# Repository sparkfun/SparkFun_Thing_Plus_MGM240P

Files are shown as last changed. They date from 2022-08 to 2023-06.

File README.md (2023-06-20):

SparkFun Thing Plus Matter - MGM240P
========================================

SparkFun Thing Plus Matter - MGM240P (https://www.sparkfun.com/products/20270)

[*SparkFun Thing Plus Matter - MGM240P (DEV-20270)*](https://www.sparkfun.com/products/20270)

The SparkFun Thing Plus Matter - MGM240P . The MGM3240P wireless module from Silicon Labs<sup>&reg;</sup> provides secure connectivity for both 802.15.4 and Bluetooth<sup>&reg;</sup> Low Energy 5.3 protocols. The module comes ready for integration into Silicon Labs' [Matter](https://www.silabs.com/wireless/matter) IoT protocol for home automation. SparkFun's [Thing Plus](https://www.sparkfun.com/thing_plus) development boards are Feather-compatible and include a Qwiic connector for easy integration into our Qwiic Connect System for solderless I<sup>2</sup>C circuits.

The SparkFun Thing Plus Matter - MGM240P includes Qwiic and LiPo battery connectors, multiple GPIO pins capable of complete multiplexing through software. The board also features the MCP73831 single-cell LiPo charger as well as the MAX17048 fuel gauge to charge and monitor a connected battery. Lastly, we've included a &micro;SD card slot for any external memory needs.

Repository Contents
-------------------

* **/Documentation** - Data sheets, additional product information
* **/Hardware** - Eagle design files (.brd, .sch)
* **/Production** - Production panel files (.brd)

Documentation
--------------
* **[Hookup Guide](https://learn.sparkfun.com/tutorials/sparkfun-thing-plus-matter---mgm240p-hookup-guide)** - Basic hookup guide for the Thing Plus Matter - MGM240P.
* **[Fritzing Part](https://github.com/sparkfun/Fritzing_Parts/blob/main/products/20270_sfe_thing_plus_matter_mgm240p.fzpz)** -  Fritzing diagrams for SparkFun products.

Product Versions
----------------
* [DEV-20270](https://www.sparkfun.com/products/20270)- Initial release of the Thing Plus Matter - MGM240P 

License Information
-------------------

This product is _**open source**_! 

Please review the LICENSE.md file for license information. 

If you have any questions or concerns on licensing, please contact technical support on our [SparkFun forums](https://forum.sparkfun.com/viewforum.php?f=152).

Distributed as-is; no warranty is given.

- Your friends at SparkFun.

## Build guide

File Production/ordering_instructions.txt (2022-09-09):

panel size, 107x201mm
PCB thickness, 1.6mm
number of layers, 4
soldermask color, Red
silkscreen color, White
oz copper, 1oz
finish, ENIG
stencils, top+bottom
pcs per panel, 12
min trace width, 0.1270mm / 0.0050in
min drill size, 0.3048mm / 0.0120in
filename to layer stackup 1/2/3/4: GTL, GL2, GL3, GBL

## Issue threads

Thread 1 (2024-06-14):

Onboard JLink UART issue

SiarheiVolkau, 2024-06-14:
I'm actually have no hope that this issue will be fixed someday, just want to warn everyone that
This piece of hardware can't be used for roles like NCP/RCP (Network/Radio Co-Processor)
because integrated onboard JLink debugger, which also tries to act as USB-to-TTL converter,
unable to do UART conversion properly.

It drops a lot of data transmitted by the MGM240 and sends a few bytes of obscure data every two seconds to MGM240
thus using any OpenThread CLI example or act as co-processor become impossible for this device, only with external debugger/USB-to-TTL converter it became feasible.

sfe-SparkFro, 2024-06-17:
Hi there, sorry to hear you're having trouble!

Could you please elaborate on what exactly you're doing to test this? I tried a quick test on my end and am unable to replicate what you describe.

For reference, I'm using the 2.0.0 release of the [SiLabs Arduino boards package](https://github.com/SiliconLabs/arduino/releases), and I uploaded the following sketch:

```
void setup() {
  Serial.begin(115200);
  Serial.println("Hello world!");
}

void loop() {
  if(Serial.available())
    Serial.print((char) Serial.read());
}
```

> sends a few bytes of obscure data every two seconds to MGM240

This is a simple serial echo sketch, which works as expected on my end. This should also detect and print any erroneous data coming from the debugger, but I've had it running for several minutes without anything unexpected happening. I've also been looking at the TX/RX pins with an oscilloscope, and the scope hasn't detected anything from the debugger.

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

The MGM240P does appear to send a couple erroneous bytes when it boots up (indicated by the 2 box symbols at the start), but that shouldn't have any effect while in operation.

Perhaps you can try doing this as well to see if your board is behaving different from mine?

> It drops a lot of data transmitted by the MGM240

I haven't tested this part yet, but given that I'm unable to replicate the above, I suspect the root problem may be something else in your setup, or your board is somehow different from mine.

Hope this helps! If you're able to test what I did above, would be great to hear your results! Thanks!

SiarheiVolkau, 2024-06-18:
Sure, here is my setup:
ArchLinux on the host PC (Silabs udev rules installed).
Simplicity Studio 5 with Gecko SDK 4.4.3 (older SDKs tried as well).
Simplicity Commander, used for flashing.

The project is the example called `Platform - I/O Stream USART Bare-metal` with no modifications.
Build it then flash via Simplicity Commander.
Use UART via minicom/picocom to communicate with the example by UART:
e.g. `picocom -b 115200 /dev/ttyACM0`
I saw `~` symbols in the output periodically and output might stop for a while.

Unfortunately for this issue, fortunately for me I can't reproduce this issue anymore, all of mine devices
start working as expected. So I'm closing this issue until I can reproduce it again.

Thanks for quick response.

sfe-SparkFro, 2024-06-18:
Thanks for sharing that info! If it does come up again, please follow up with replication instructions so we can try to figure out the root problem. I suspect, and I hope, that the problem is not with the J-Link chip, but would need to do more testing to actually determine that.

Closed 2024-06-18.

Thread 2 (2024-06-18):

Change baudrate on integrated USB-to-UART

SiarheiVolkau, 2024-06-18:
Is there any way to do so?
I'm able to change baudrate in the source code.
And say communication program to set specific baudrate (picocom).

But it seems 115200 is the only working setup.

It's crucial to get faster baudrates if this device used as network / radio coprocessor as it dramatically reduces latencies.

My setup:
- ArchLinux
- Simplicity Studio v5
- Gecko SDK 4.4.3
- `iostream-usart-baremetal` example used, with changed baudrate to 230400 in `IO Stream: USART (vcom)` software component.
- `picocom -b 230400 /dev/ttyACM0`

sfe-SparkFro, 2024-06-18:
I am also seeing this, using the same Arduino sketch I shared in #1. I will follow up with SiLabs to see if other baud rates can be selected.

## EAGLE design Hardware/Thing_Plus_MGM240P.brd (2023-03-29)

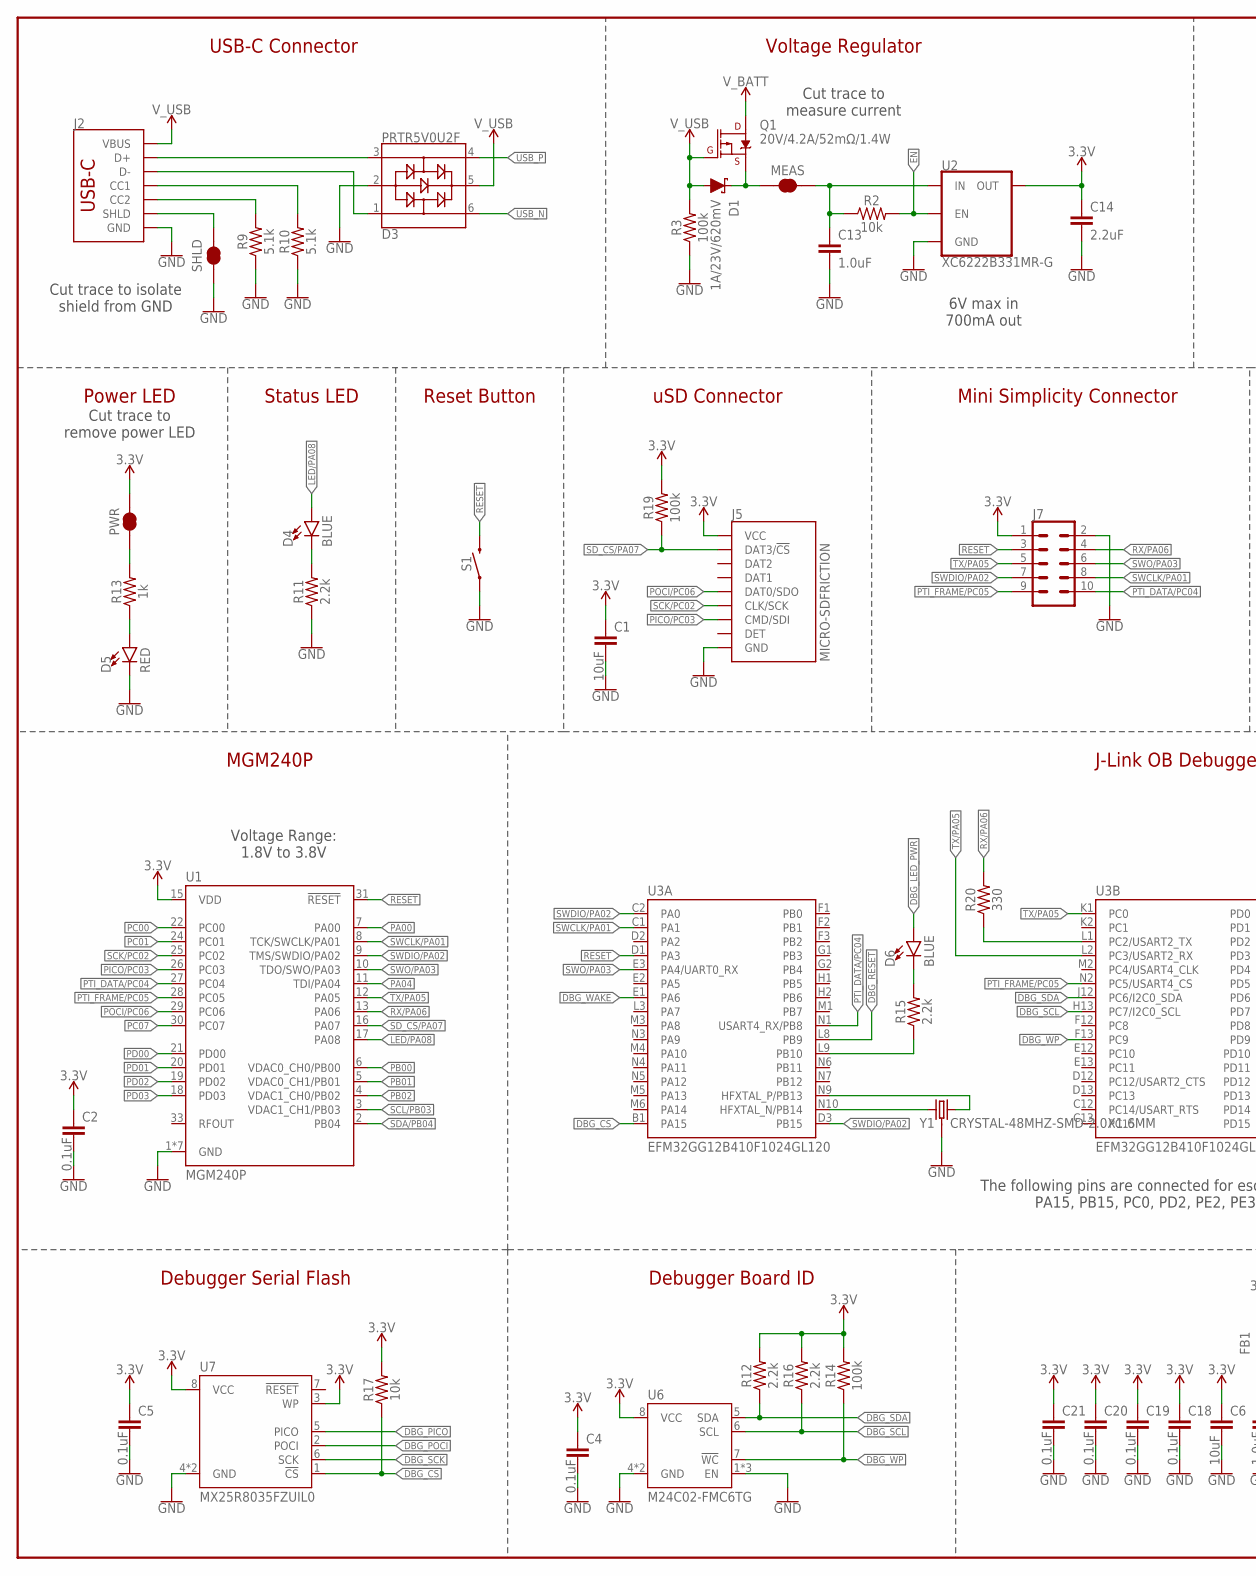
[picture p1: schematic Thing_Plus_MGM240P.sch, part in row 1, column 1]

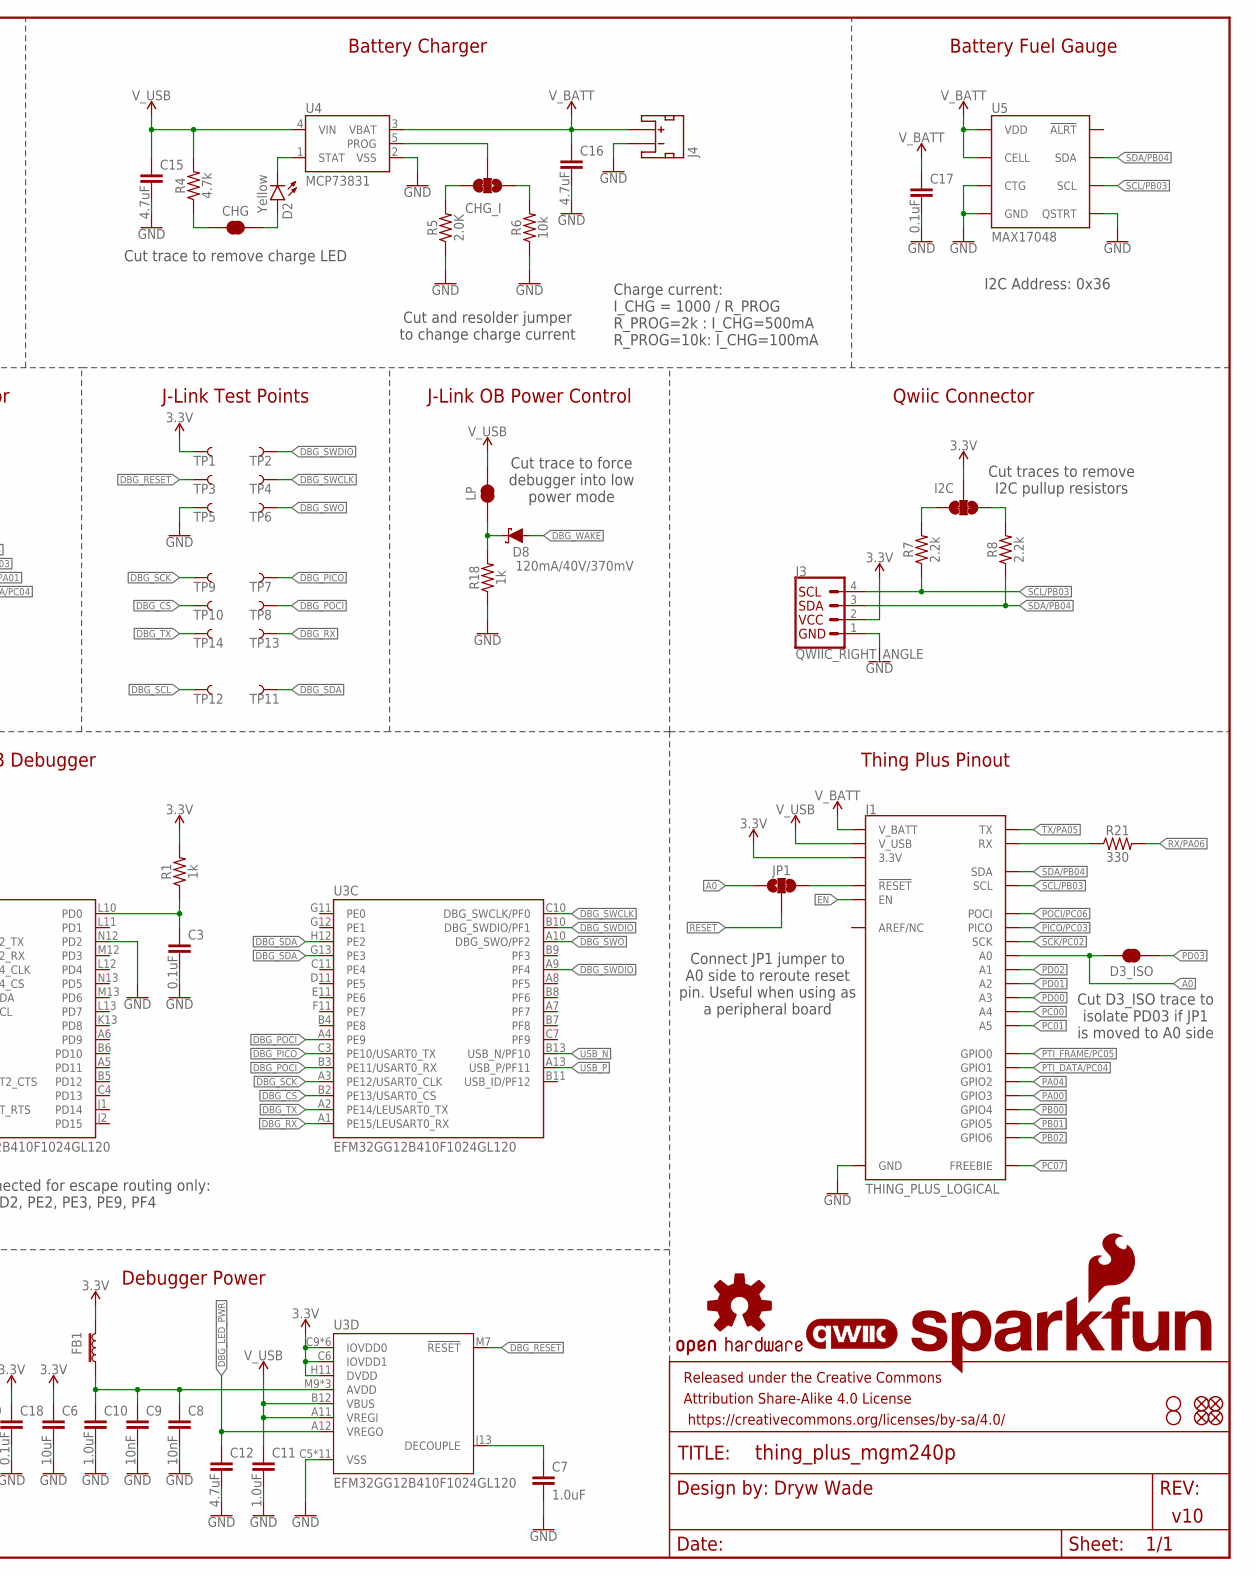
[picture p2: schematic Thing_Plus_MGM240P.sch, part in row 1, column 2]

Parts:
C1, C6: 10uF; 0402-TIGHT
C2, C3, C4, C5, C17, C18, C19, C20, C21: 0.1uF; 0402-TIGHT
C7: 1.0uF; 0603
C8, C9: 10nF; 0402-TIGHT
C10, C11, C13: 1.0uF; 0402-TIGHT
C12, C15, C16: 4.7uF; 0402-TIGHT
C14: 2.2uF; 0402-TIGHT
CHG: JUMPER-SMT_2_NC_TRACE_SILK; SMT-JUMPER_2_NC_TRACE_SILK
CHG_I: JUMPER-SMT_3_1-NC_TRACE_SILK; SMT-JUMPER_3_1-NC_TRACE_SILK
D1: 1A/23V/620mV; SOD-323
D2: Yellow; LED-0603
D3: PRTR5V0U2F; SOT886
D3_ISO: JUMPER-SMT_2_NC_TRACE_SILK; SMT-JUMPER_2_NC_TRACE_SILK
D4, D6: BLUE; LED-0603
D5: RED; LED-0603
D8: 120mA/40V/370mV; SOD-523
FB1: FERRITE_BEAD-120_OHM-0402T; 0402-TIGHT
FD1, FD2, FD3, FD4: FIDUCIAL1X2; FIDUCIAL-1X2
FRAME1: FRAME-LEDGER; CREATIVE_COMMONS
H1, H2: STAND-OFF
I2C: JUMPER-SMT_3_2-NC_TRACE_SILK; SMT-JUMPER_3_2-NC_TRACE_SILK
J1: THING_PLUS_LOGICAL; THING_PLUS
J2: USB Female Type C Connector; USB-C-16P-4LAYER-ISOLATED
J3: QWIIC_RIGHT_ANGLE; JST04_1MM_RA
J4: JST_2MM_MALE; JST-2-SMD
J5: MICRO-SDFRICTION; MICROSD_TINY
J7: CONN_05X20.05_IN_PTH_SILK; 2X5_PTH_SILK_.05
JP1: JUMPER-SMT_3_1-NC_TRACE_SILK; SMT-JUMPER_3_1-NC_TRACE_SILK
LOGO1: SFE_LOGO_NAME_FLAME.1_INCH; SFE_LOGO_NAME_FLAME_.1
LOGO2: QWIIC_LOGO_3MM; QWIIC_3MM
LOGO3: OSHW-LOGOS; OSHW-LOGO-S
LP: JUMPER-SMT_2_NC_TRACE_SILK; SMT-JUMPER_2_NC_TRACE_SILK
MEAS: JUMPER-COMBO_2_NC_TRACE; COMBO-JUMPER_2_NC_TRACE
PWR: JUMPER-SMT_2_NC_TRACE_SILK; SMT-JUMPER_2_NC_TRACE_SILK
Q1: 20V/4.2A/52mΩ/1.4W; SOT23-3
R1, R13, R18: 1k; 0402-TIGHT
R2, R6, R17: 10k; 0402-TIGHT
R3, R14, R19: 100k; 0402-TIGHT
R4: 4.7k; 0402-TIGHT
R5: 2.0K; 0402-TIGHT
R7, R8, R11, R12, R15, R16: 2.2k; 0402-TIGHT
R9, R10: 5.1k; 0402-TIGHT
R20, R21: 330; 0402-TIGHT
S1: MOMENTARY-SWITCH-SPST-SMD-4.6X2.8MM; TACTILE_SWITCH_SMD_4.6X2.8MM
SHLD: JUMPER-SMT_2_NC_TRACE_SILK; SMT-JUMPER_2_NC_TRACE_SILK
TP1, TP2, TP3, TP4, TP5, TP6, TP7, TP8, TP9, TP10, TP11, TP12, TP13, TP14: TEST-POINT3; PAD.03X.03
U1: MGM240P
U2: XC6222B331MR-G; SOT23-5
U3: EFM32GG12B410F1024GL120; BGA120
U4: MCP73831; SOT23-5
U5: MAX17048; DFN-8
U6: M24C02-FMC6TG; DFN8_2X3MM
U7: MX25R8035FZUIL0; USON-8_2X3MM
Y1: CRYSTAL-48MHZ-SMD-2.0X1.6MM; CRYSTAL-SMD-2.0X1.6MM-ECS

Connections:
3.3V: C1.1, C2.1, C4.1, C5.1, C6.1, C14.1, C18.1, C19.1, C20.1, C21.1, FB1.2, I2C.2, J1.27 (3.3V), J3.2, J5.4 (VCC), J7.1, PWR.2, R1.2, R12.2, R14.2, R16.2, R17.2, R19.2, TP1.1, U1.15 (VDD), U2.5 (OUT), U3.C6 (IOVDD1), U3.C9 (IOVDD0), U3.G3 (IOVDD0), U3.H11 (DVDD), U3.J11 (IOVDD0), U3.K3 (IOVDD0), U3.L4 (IOVDD0), U3.L7 (IOVDD0), U6.8 (VCC), U7.3 (WP), U7.8 (VCC)
!DBG_RESET!: TP3.1, U3.L8 (PB9), U3.M7 (!RESET!)
!RESET!: J7.3, JP1.2, S1.3 (2), S1.4 (2), U1.31 (!RESET!), U3.D1 (PA3)
!SD_CS!/PA07: J5.2 (DAT3/!CS!), R19.1, U1.16 (PA07)
A0: D3_ISO.2, J1.24 (A0), JP1.1
DBG_CS: R17.1, TP10.1, U3.B1 (PA15), U3.B2 (PE13/USART0_CS), U7.1 (!CS!)
DBG_LED_PWR: C12.1, D6.A, U3.A12 (VREGO)
DBG_PICO: TP7.1, U3.C3 (PE10/USART0_TX), U7.5 (PICO)
DBG_POCI: TP8.1, U3.A4 (PE9), U3.B3 (PE11/USART0_RX), U7.2 (POCI)
DBG_RX: TP13.1, U3.A1 (PE15/LEUSART0_RX)
DBG_SCK: TP9.1, U3.A3 (PE12/USART0_CLK), U7.6 (SCK)
DBG_SCL: R16.1, TP12.1, U3.H13 (PC7/I2C0_SCL), U6.6 (SCL)
DBG_SDA: R12.1, TP11.1, U3.G13 (PE3), U3.H12 (PE2), U3.J12 (PC6/I2C0_SDA), U6.5 (SDA)
DBG_SWCLK: TP4.1, U3.C10 (DBG_SWCLK/PF0)
DBG_SWDIO: TP2.1, U3.A9 (PF4), U3.B10 (DBG_SWDIO/PF1)
DBG_SWO: TP6.1, U3.A10 (DBG_SWO/PF2)
DBG_TX: TP14.1, U3.A2 (PE14/LEUSART0_TX)
DBG_WAKE: D8.A, U3.E1 (PA6)
DBG_WP: R14.1, U3.F13 (PC9), U6.7 (!WC!)
EN: J1.11 (EN), R2.2, U2.3 (EN)
GND: C1.2, C2.2, C3.2, C4.2, C5.2, C6.2, C7.2, C8.2, C9.2, C10.2, C11.2, C12.2, C13.2, C14.2, C15.2, C16.2, C17.2, C18.2, C19.2, C20.2, C21.2, D3.2, D5.C, J1.25 (GND), J2.GND, J2.GND2 (GND), J3.1, J4.1 (-), J5.6 (GND), J5.GND1 (GND), J5.GND2 (GND), J5.GND3 (GND), J5.GND4 (GND), J5.GND5 (GND), J5.GND6 (GND), J7.2, R3.1, R5.1, R6.1, R9.1, R10.1, R11.1, R18.1, S1.1, S1.2 (1), SHLD.1, TP5.1, U1.1 (GND), U1.14 (GND), U1.23 (GND), U1.32 (GND), U1.34 (GND), U1.35 (GND), U1.36 (GND), U2.2 (GND), U3.C5 (VSS), U3.C8 (VSS), U3.H3 (VSS), U3.J3 (VSS), U3.K11 (VSS), U3.K12 (VSS), U3.L5 (VSS), U3.L6 (VSS), U3.M8 (VSS), U3.M11 (VSS), U3.N8 (VSS), U3.N12 (PD2), U4.2 (VSS), U5.1 (CTG), U5.4 (GND), U5.6 (QSTRT), U5.9 (GND), U6.1 (EN), U6.2 (EN), U6.3 (EN), U6.4 (GND), U6.EPAD (GND), U7.4 (GND), U7.EPAD (GND), Y1.2 (GND), Y1.4 (GND)
LED/PA08: D4.A, U1.17 (PA08)
unnamed: D4.C, R11.2
unnamed: PWR.1, R13.2
unnamed: CHG.2, D2.A
unnamed: CHG_I.1, R6.2
unnamed: D2.C, U4.1 (STAT)
unnamed: CHG_I.3, R5.2
unnamed: D1.C, MEAS.1, MEAS.3 (1), Q1.2 (S)
unnamed: D5.A, R13.1
unnamed: CHG_I.2, U4.5 (PROG)
unnamed: CHG.1, R4.1
unnamed: I2C.3, R7.2
unnamed: C3.1, R1.1, U3.L10 (PD0)
unnamed: I2C.1, R8.2
unnamed: J2.B5 (CC2), R9.2
unnamed: J2.A5 (CC1), R10.2
unnamed: D3.3, J2.A6 (D+), J2.B6 (D+)
unnamed: C7.1, U3.J13 (DECOUPLE)
unnamed: D3.1, J2.A7 (D-), J2.B7 (D-)
unnamed: C8.1, C9.1, C10.1, FB1.1, U3.M9 (AVDD), U3.M10 (AVDD), U3.N11 (AVDD)
unnamed: R15.1, U3.L9 (PB10)
unnamed: D6.C, R15.2
unnamed: U3.N10 (HFXTAL_N/PB14), Y1.1
unnamed: U3.N9 (HFXTAL_P/PB13), Y1.3 (2)
unnamed: D8.C, LP.1, R18.2
unnamed: R20.1, U3.L1 (PC2/USART2_TX)
unnamed: J1.15 (RX), R21.1
unnamed: C13.1, MEAS.2, MEAS.4 (2), R2.1, U2.1 (IN)
unnamed: J1.28 (!RESET), JP1.3
PA00: J1.6 (GPIO3), U1.7 (PA00)
PA04: J1.7 (GPIO2), U1.11 (TDI/PA04)
PB00: J1.5 (GPIO4), U1.6 (VDAC0_CH0/PB00)
PB01: J1.4 (GPIO5), U1.5 (VDAC0_CH1/PB01)
PB02: J1.3 (GPIO6), U1.4 (VDAC1_CH0/PB02)
PC00: J1.20 (A4), U1.22 (PC00)
PC01: J1.19 (A5), U1.24 (PC01)
PC07: J1.13 (FREEBIE), U1.30 (PC07)
PD00: J1.21 (A3), U1.21 (PD00)
PD01: J1.22 (A2), U1.20 (PD01)
PD02: J1.23 (A1), U1.19 (PD02)
PD03: D3_ISO.1, U1.18 (PD03)
PICO/PC03: J1.17 (PICO), J5.3 (CMD/SDI), U1.26 (PC03)
POCI/PC06: J1.16 (POCI), J5.7 (DAT0/SDO), U1.29 (PC06)
PTI_DATA/PC04: J1.8 (GPIO1), J7.10, U1.27 (PC04), U3.N1 (USART4_RX/PB8)
PTI_FRAME/PC05: J1.9 (GPIO0), J7.9, U1.28 (PC05), U3.N2 (PC5/USART4_CS)
RX/PA06: J7.4, R20.2, R21.2, U1.13 (PA06)
SCK/PC02: J1.18 (SCK), J5.5 (CLK/SCK), U1.25 (PC02)
SCL/PB03: J1.2 (SCL), J3.4, R7.1, U1.3 (VDAC1_CH1/PB03), U5.7 (SCL)
SDA/PB04: J1.1 (SDA), J3.3, R8.1, U1.2 (PB04), U5.8 (SDA)
SHLD: J2.SHLD1 (SHLD), J2.SHLD2 (SHLD), J2.SHLD3 (SHLD), J2.SHLD4 (SHLD), J2.SHLD5 (SHLD), J2.SHLD6 (SHLD), J2.SHLD7 (SHLD), J2.SHLD8 (SHLD), SHLD.2
SWCLK/PA01: J7.8, U1.8 (TCK/SWCLK/PA01), U3.C1 (PA1)
SWDIO/PA02: J7.7, U1.9 (TMS/SWDIO/PA02), U3.C2 (PA0), U3.D3 (PB15)
SWO/PA03: J7.6, U1.10 (TDO/SWO/PA03), U3.E3 (PA4/UART0_RX)
TX/PA05: J1.14 (TX), J7.5, U1.12 (PA05), U3.K1 (PC0), U3.L2 (PC3/USART2_RX)
USB_N: D3.6, U3.B13 (USB_N/PF10)
USB_P: D3.4, U3.A13 (USB_P/PF11)
V_BATT: C16.1, C17.1, J1.12 (V_BATT), J4.2 (+), Q1.3 (D), U4.3 (VBAT), U5.2 (CELL), U5.3 (VDD)
V_USB: C11.1, C15.1, D1.A, D3.5, J1.10 (V_USB), J2.VBUS1 (VBUS), J2.VBUS2 (VBUS), LP.2, Q1.1 (G), R3.2, R4.2, U3.A11 (VREGI), U3.B12 (VBUS), U4.4 (VIN)

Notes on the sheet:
Voltage Regulator
Battery Charger
Battery Fuel Gauge
USB-C Connector
I2C Address: 0x36
Cut trace to remove charge LED
Charge current: I_CHG = 1000 / R_PROG R_PROG=2k : I_CHG=500mA R_PROG=10k: I_CHG=100mA
Cut and resolder jumper to change charge current
6V max in 700mA out
Cut trace to isolate shield from GND
Cut trace to measure current
Qwiic Connector
uSD Connector
Cut traces to remove I2C pullup resistors
Mini Simplicity Connector
Status LED
J-Link Test Points
J-Link OB Debugger
Thing Plus Pinout
MGM240P
J-Link OB Power Control
Dryw Wade
v10
Cut trace to remove power LED
Reset Button
Power LED
Voltage Range: 1.8V to 3.8V
Debugger Serial Flash
Debugger Board ID
Debugger Power
Cut trace to force debugger into low power mode
Connect JP1 jumper to A0 side to reroute reset pin. Useful when using as a peripheral board
Cut D3_ISO trace to isolate PD03 if JP1 is moved to A0 side
The following pins are connected for escape routing only: PA15, PB15, PC0, PD2, PE2, PE3, PE9, PF4

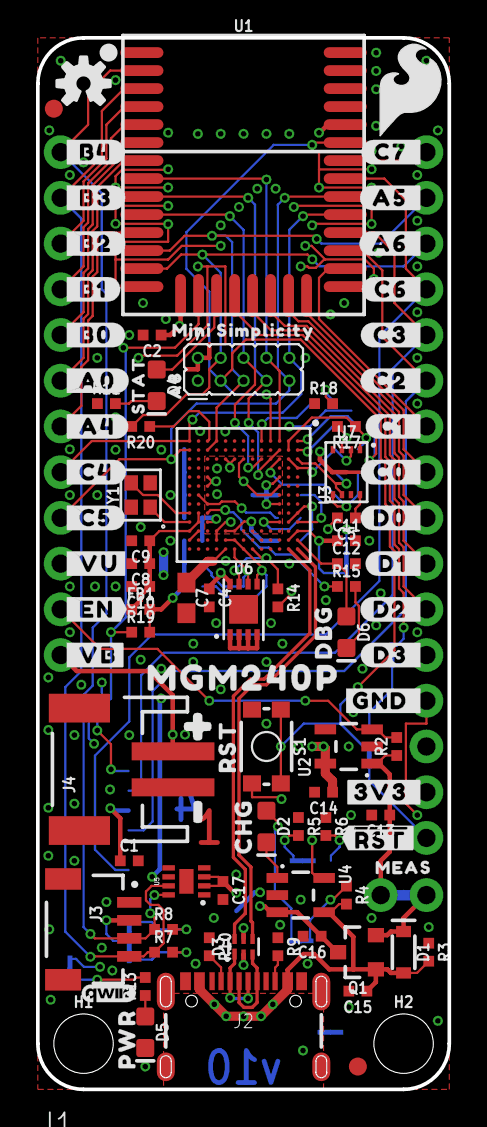
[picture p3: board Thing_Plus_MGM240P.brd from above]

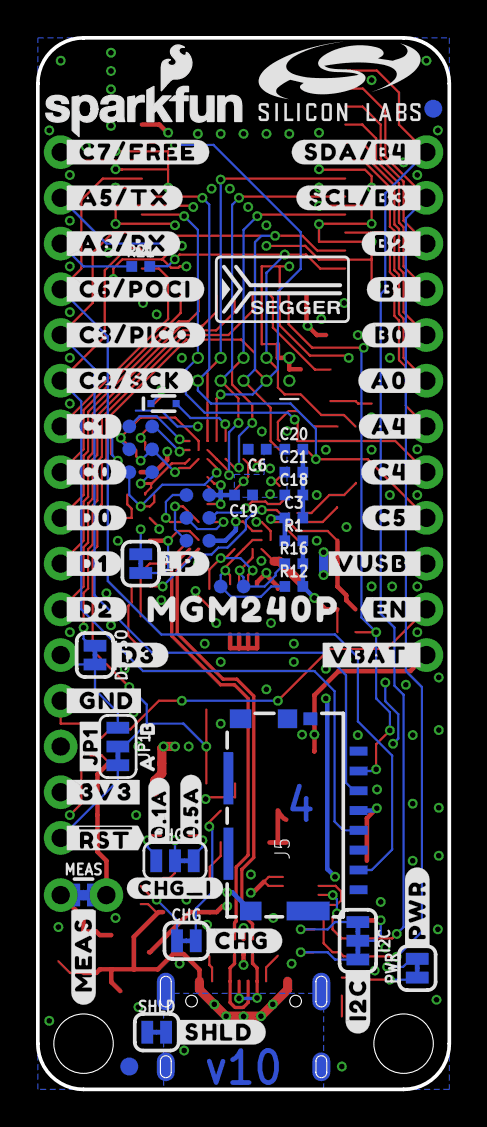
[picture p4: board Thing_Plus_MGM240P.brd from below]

Board: 4 copper layers, 22.9 x 58.4 mm, 182 parts (80 on the bottom side), 79 nets.

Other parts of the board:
U$1: #_B4#0
U$2: #_B3#0
U$3: #_B2#0
U$4: #_B1#0
U$5: #SHLD#0
U$6: #_B0#0
U$7: #_A0#0
U$8: #_A4#0
U$9: #_C5#0
U$10: #_C4#0
U$11: #C7_#0
U$12: #A5_#0
U$13: #A6_#0
U$14: #C6_#0
U$15: #C3_#0
U$16: #C2_#0
U$17: #C1_#0
U$18: #C0_#0
U$19: #PWR#0
U$20: PWR0
U$21: #GND_#0
U$22: #3V3_#0
U$23, U$58: MGM240P0
U$24: #D0_#0
U$25: #_VB#0
U$26: #_VU#0
U$27: #_EN#0
U$28: ##RST##0
U$29: SFE_LOGO_FLAME_.2
U$30: #0
U$31: #1
U$32: #D1_#0
U$33: #LP#0
U$34: #_A6#RX#0
U$35: #_C6#POCI#0
U$36: #_C3#PICO#0
U$37: #_C2#SCK#0
U$38: MINI_SIMPLICITY0
U$39: #_C1#0
U$40: #_C0#0
U$41: #_D0#0
U$42: #_D1#0
U$43: #_GND#0
U$44: #_3V3#0
U$45: #_#RST##0
U$46: #_D2#0
U$47: SEGGER_LOGO_7.5MM
U$48: #C4_#0
U$49: #C5_#0
U$50: #A4_#0
U$51: #A0_#0
U$52: #B0_#0
U$53: #B2_#0
U$54: #B1_#0
U$55: #VBAT_#0
U$56: #VUSB_#0
U$57: #EN_#0
U$59: #MEAS#0
U$60: #CHG#0
U$61: #I2C#0
U$62: #D2_#0
U$63: #0#5A#0
U$64: #0#1A#0
U$66: MEAS81
U$67: CHG0
U$68: STAT0
U$69: #JP1#0
U$70: RST0
U$71: #_A5#TX#0
U$72: A80
U$73: #SDA#B4_#0
U$74: #SCL#B3_#0
U$75: ORDERING_INSTRUCTIONS
U$76: FOUR_LAYER_WARNING
U$77: #D3_#0
U$78: DBG0
U$79: #_C7#FREE#0
U$80: A0
U$81: B0
U$82: #D3#4
U$83: #CHG_I#0
U$84: SILICON_LABS_LOGO_9MM

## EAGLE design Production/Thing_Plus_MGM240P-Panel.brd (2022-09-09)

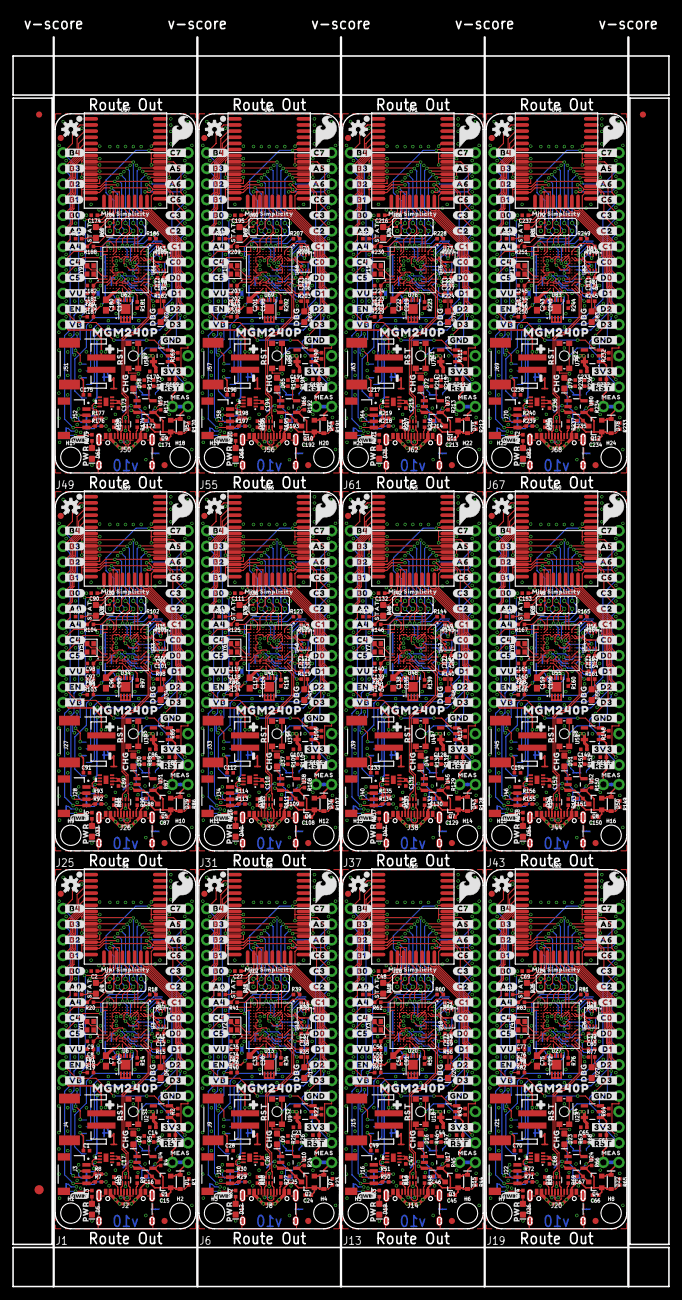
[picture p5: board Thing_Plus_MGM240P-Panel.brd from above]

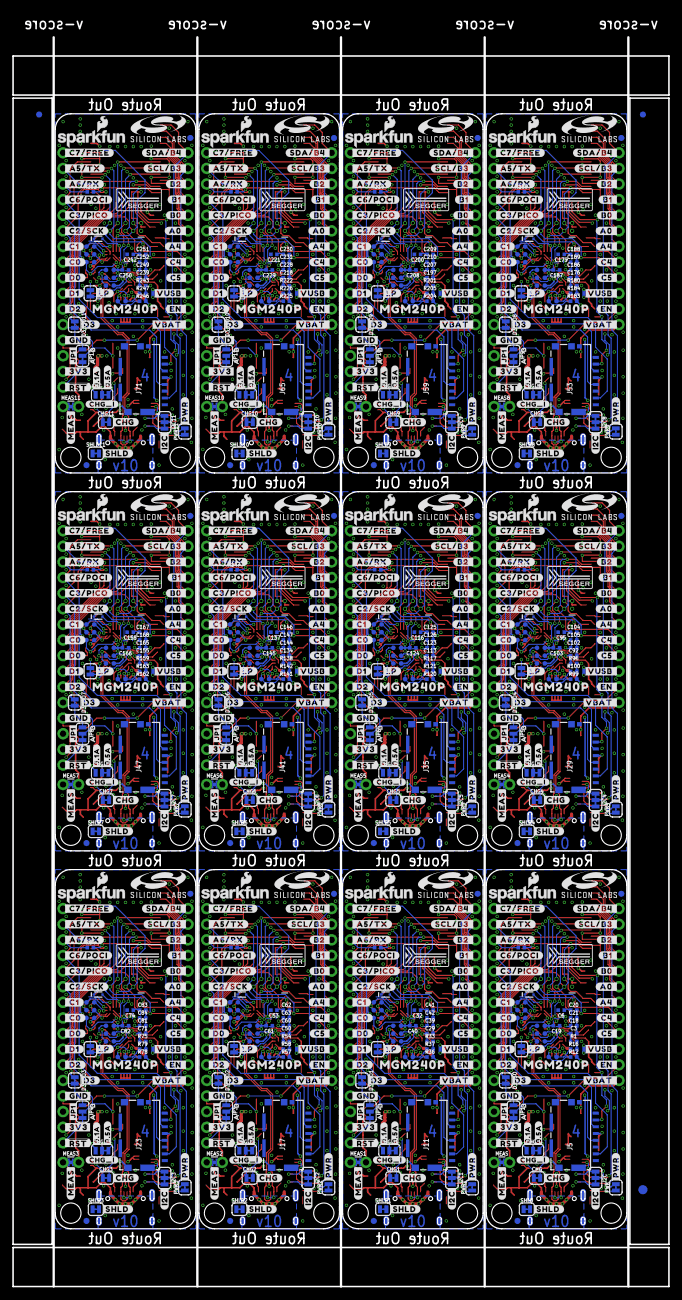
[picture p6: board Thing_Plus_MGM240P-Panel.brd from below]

Board: 4 copper layers, 106.7 x 203.2 mm, 2178 parts (963 on the bottom side), 948 nets.

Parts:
C1, C6, C28, C32, C49, C53, C70, C74, C91, C95, C112, C116, C133, C137, C154, C158, C175, C179, C196, C200, C217, C221, C238, C242: 10uF; 0402-TIGHT
C2, C3, C4, C5, C17, C18, C19, C20, C21, C26, C27, C29, C30, C31, C39, C40, C41, C42, C47, C48, C50, C51, C52, C60, C61, C62, C63, C68, C69, C71, C72, C73, C81, C82, C83, C84, C89, C90, C92, C93, C94, C102, C103, C104, C105, C110, C111, C113, C114, C115, C123, C124, C125, C126, C131, C132, C134, C135, C136, C144, C145, C146, C147, C152, C153, C155, C156, C157, C165, C166, C167, C168, C173, C174, C176, C177, C178, C186, C187, C188, C189, C194, C195, C197, C198, C199, C207, C208, C209, C210, C215, C216, C218, C219, C220, C228, C229, C230, C231, C236, C237, C239, C240, C241, C249, C250, C251, C252: 0.1uF; 0402-TIGHT
C7, C33, C54, C75, C96, C117, C138, C159, C180, C201, C222, C243: 1.0uF; 0603
C8, C9, C34, C35, C55, C56, C76, C77, C97, C98, C118, C119, C139, C140, C160, C161, C181, C182, C202, C203, C223, C224, C244, C245: 10nF; 0402-TIGHT
C10, C11, C13, C22, C36, C37, C43, C57, C58, C64, C78, C79, C85, C99, C100, C106, C120, C121, C127, C141, C142, C148, C162, C163, C169, C183, C184, C190, C204, C205, C211, C225, C226, C232, C246, C247: 1.0uF; 0402-TIGHT
C12, C15, C16, C24, C25, C38, C45, C46, C59, C66, C67, C80, C87, C88, C101, C108, C109, C122, C129, C130, C143, C150, C151, C164, C171, C172, C185, C192, C193, C206, C213, C214, C227, C234, C235, C248: 4.7uF; 0402-TIGHT
C14, C23, C44, C65, C86, C107, C128, C149, C170, C191, C212, C233: 2.2uF; 0402-TIGHT
CHG, CHG1, CHG2, CHG3, CHG4, CHG5, CHG6, CHG7, CHG8, CHG9, CHG10, CHG11: JUMPER-SMT_2_NC_TRACE_SILK; SMT-JUMPER_2_NC_TRACE_SILK
CHG_I, CHG_I1, CHG_I2, CHG_I3, CHG_I4, CHG_I5, CHG_I6, CHG_I7, CHG_I8, CHG_I9, CHG_I10, CHG_I11: JUMPER-SMT_3_1-NC_TRACE_SILK; SMT-JUMPER_3_1-NC_TRACE_SILK
D1, D7, D15, D22, D29, D36, D43, D50, D57, D64, D71, D78: 1A/23V/620mV; SOD-323
D2, D9, D16, D23, D30, D37, D44, D51, D58, D65, D72, D79: Yellow; LED-0603
D3, D10, D17, D24, D31, D38, D45, D52, D59, D66, D73, D80: PRTR5V0U2F; SOT886
D3_ISO, D3_ISO1, D3_ISO2, D3_ISO3, D3_ISO4, D3_ISO5, D3_ISO6, D3_ISO7, D3_ISO8, D3_ISO9, D3_ISO10, D3_ISO11: JUMPER-SMT_2_NC_TRACE_SILK; SMT-JUMPER_2_NC_TRACE_SILK
D4, D6, D11, D13, D18, D20, D25, D27, D32, D34, D39, D41, D46, D48, D53, D55, D60, D62, D67, D69, D74, D76, D81, D83: BLUE; LED-0603
D5, D12, D19, D26, D33, D40, D47, D54, D61, D68, D75, D82: RED; LED-0603
D8, D14, D21, D28, D35, D42, D49, D56, D63, D70, D77, D84: 120mA/40V/370mV; SOD-523
E$1, E$2, E$3, E$4: FIDUCIAL-1X2
E$5, E$6: FIDUCIAL-1.5X3
FB1, FB2, FB3, FB4, FB5, FB6, FB7, FB8, FB9, FB10, FB11, FB12: FERRITE_BEAD-120_OHM-0402T; 0402-TIGHT
FD1, FD2, FD3, FD4, FD5, FD6, FD7, FD8, FD9, FD10, FD11, FD12, FD13, FD14, FD15, FD16, FD17, FD18, FD19, FD20, FD21, FD22, FD23, FD24, FD25, FD26, FD27, FD28, FD29, FD30, FD31, FD32, FD33, FD34, FD35, FD36, FD37, FD38, FD39, FD40, FD41, FD42, FD43, FD44, FD45, FD46, FD47, FD48: FIDUCIAL1X2; FIDUCIAL-1X2
H1, H2, H3, H4, H5, H6, H7, H8, H9, H10, H11, H12, H13, H14, H15, H16, H17, H18, H19, H20, H21, H22, H23, H24: STAND-OFF
I2C, I2C1, I2C2, I2C3, I2C4, I2C5, I2C6, I2C7, I2C8, I2C9, I2C10, I2C11: JUMPER-SMT_3_2-NC_TRACE_SILK; SMT-JUMPER_3_2-NC_TRACE_SILK
J1, J6, J13, J19, J25, J31, J37, J43, J49, J55, J61, J67: THING_PLUS_LOGICAL; THING_PLUS
J2, J8, J14, J20, J26, J32, J38, J44, J50, J56, J62, J68: USB Female Type C Connector; USB-C-16P-4LAYER-ISOLATED
J3, J10, J16, J22, J28, J34, J40, J46, J52, J58, J64, J70: QWIIC_RIGHT_ANGLE; JST04_1MM_RA
J4, J9, J15, J21, J27, J33, J39, J45, J51, J57, J63, J69: JST-2-SMD
J5, J11, J17, J23, J29, J35, J41, J47, J53, J59, J65, J71: MICRO-SDFRICTION; MICROSD_TINY
J7, J12, J18, J24, J30, J36, J42, J48, J54, J60, J66, J72: 2X5_PTH_SILK_.05
JP1, JP2, JP3, JP4, JP5, JP6, JP7, JP8, JP9, JP10, JP11, JP12: JUMPER-SMT_3_1-NC_TRACE_SILK; SMT-JUMPER_3_1-NC_TRACE_SILK
LOGO1, LOGO4, LOGO7, LOGO10, LOGO13, LOGO16, LOGO19, LOGO22, LOGO25, LOGO28, LOGO31, LOGO34: SFE_LOGO_NAME_FLAME.1_INCH; SFE_LOGO_NAME_FLAME_.1
LOGO2, LOGO5, LOGO8, LOGO11, LOGO14, LOGO17, LOGO20, LOGO23, LOGO26, LOGO29, LOGO32, LOGO35: QWIIC_LOGO_3MM; QWIIC_3MM
LOGO3, LOGO6, LOGO9, LOGO12, LOGO15, LOGO18, LOGO21, LOGO24, LOGO27, LOGO30, LOGO33, LOGO36: OSHW-LOGOS; OSHW-LOGO-S
LP, LP1, LP2, LP3, LP4, LP5, LP6, LP7, LP8, LP9, LP10, LP11: JUMPER-SMT_2_NC_TRACE_SILK; SMT-JUMPER_2_NC_TRACE_SILK
MEAS, MEAS1, MEAS2, MEAS3, MEAS4, MEAS5, MEAS6, MEAS7, MEAS8, MEAS9, MEAS10, MEAS11: JUMPER-COMBO_2_NC_TRACE; COMBO-JUMPER_2_NC_TRACE
PWR, PWR1, PWR2, PWR3, PWR4, PWR5, PWR6, PWR7, PWR8, PWR9, PWR10, PWR11: JUMPER-SMT_2_NC_TRACE_SILK; SMT-JUMPER_2_NC_TRACE_SILK
Q1, Q2, Q3, Q4, Q5, Q6, Q7, Q8, Q9, Q10, Q11, Q12: 20V/4.2A/52mΩ/1.4W; SOT23-3
R1, R13, R18, R32, R33, R39, R53, R54, R60, R74, R75, R81, R95, R96, R102, R116, R117, R123, R137, R138, R144, R158, R159, R165, R179, R180, R186, R200, R201, R207, R221, R222, R228, R242, R243, R249: 1k; 0402-TIGHT
R2, R3, R6, R17, R22, R23, R26, R38, R43, R44, R47, R59, R64, R65, R68, R80, R85, R86, R89, R101, R106, R107, R110, R122, R127, R128, R131, R143, R148, R149, R152, R164, R169, R170, R173, R185, R190, R191, R194, R206, R211, R212, R215, R227, R232, R233, R236, R248: 10k; 0402-TIGHT
R4, R24, R45, R66, R87, R108, R129, R150, R171, R192, R213, R234: 4.7k; 0402-TIGHT
R5, R25, R46, R67, R88, R109, R130, R151, R172, R193, R214, R235: 2.0K; 0402-TIGHT
R7, R8, R11, R12, R15, R16, R29, R30, R31, R35, R36, R37, R50, R51, R52, R56, R57, R58, R71, R72, R73, R77, R78, R79, R92, R93, R94, R98, R99, R100, R113, R114, R115, R119, R120, R121, R134, R135, R136, R140, R141, R142, R155, R156, R157, R161, R162, R163, R176, R177, R178, R182, R183, R184, R197, R198, R199, R203, R204, R205, R218, R219, R220, R224, R225, R226, R239, R240, R241, R245, R246, R247: 2.2k; 0402-TIGHT
R9, R10, R27, R28, R48, R49, R69, R70, R90, R91, R111, R112, R132, R133, R153, R154, R174, R175, R195, R196, R216, R217, R237, R238: 5.1k; 0402-TIGHT
R14, R19, R34, R40, R55, R61, R76, R82, R97, R103, R118, R124, R139, R145, R160, R166, R181, R187, R202, R208, R223, R229, R244, R250: 100k; 0402-TIGHT
R20, R21, R41, R42, R62, R63, R83, R84, R104, R105, R125, R126, R146, R147, R167, R168, R188, R189, R209, R210, R230, R231, R251, R252: 330; 0402-TIGHT
S1, S2, S3, S4, S5, S6, S7, S8, S9, S10, S11, S12: MOMENTARY-SWITCH-SPST-SMD-4.6X2.8MM; TACTILE_SWITCH_SMD_4.6X2.8MM
SHLD, SHLD1, SHLD2, SHLD3, SHLD4, SHLD5, SHLD6, SHLD7, SHLD8, SHLD9, SHLD10, SHLD11: JUMPER-SMT_2_NC_TRACE_SILK; SMT-JUMPER_2_NC_TRACE_SILK
TP1, TP2, TP3, TP4, TP5, TP6, TP7, TP8, TP9, TP10, TP11, TP12, TP13, TP14, TP15, TP16, TP17, TP18, TP19, TP20, TP21, TP22, TP23, TP24, TP25, TP26, TP27, TP28, TP29, TP30, TP31, TP32, TP33, TP34, TP35, TP36, TP37, TP38, TP39, TP40, TP41, TP42, TP43, TP44, TP45, TP46, TP47, TP48, TP49, TP50, TP51, TP52, TP53, TP54, TP55, TP56, TP57, TP58, TP59, TP60, TP61, TP62, TP63, TP64, TP65, TP66, TP67, TP68, TP69, TP70, TP71, TP72, TP73, TP74, TP75, TP76, TP77, TP78, TP79, TP80, TP81, TP82, TP83, TP84, TP85, TP86, TP87, TP88, TP89, TP90, TP91, TP92, TP93, TP94, TP95, TP96, TP97, TP98, TP99, TP100, TP101, TP102, TP103, TP104, TP105, TP106, TP107, TP108, TP109, TP110, TP111, TP112, TP113, TP114, TP115, TP116, TP117, TP118, TP119, TP120, TP121, TP122, TP123, TP124, TP125, TP126, TP127, TP128, TP129, TP130, TP131, TP132, TP133, TP134, TP135, TP136, TP137, TP138, TP139, TP140, TP141, TP142, TP143, TP144, TP145, TP146, TP147, TP148, TP149, TP150, TP151, TP152, TP153, TP154, TP155, TP156, TP157, TP158, TP159, TP160, TP161, TP162, TP163, TP164, TP165, TP166, TP167, TP168: TEST-POINT3; PAD.03X.03
U1, U8, U15, U22, U29, U36, U43, U50, U57, U64, U71, U78: MGM240P
U2, U9, U16, U23, U30, U37, U44, U51, U58, U65, U72, U79: XC6222B331MR-G; SOT23-5
U3, U12, U19, U26, U33, U40, U47, U54, U61, U68, U75, U82: EFM32GG12B410F1024GL120
U4, U10, U17, U24, U31, U38, U45, U52, U59, U66, U73, U80: MCP73831; SOT23-5
U5, U11, U18, U25, U32, U39, U46, U53, U60, U67, U74, U81: MAX17048; DFN-8
U6, U13, U20, U27, U34, U41, U48, U55, U62, U69, U76, U83: M24C02-FMC6TG
U7, U14, U21, U28, U35, U42, U49, U56, U63, U70, U77, U84: MX25R8035FZUIL0
U$1, U$110, U$193, U$276, U$359, U$442, U$525, U$608, U$691, U$774, U$857, U$940: #_B4#0
U$2, U$111, U$194, U$277, U$360, U$443, U$526, U$609, U$692, U$775, U$858, U$941: #_B3#0
U$3, U$112, U$195, U$278, U$361, U$444, U$527, U$610, U$693, U$776, U$859, U$942: #_B2#0
U$4, U$113, U$196, U$279, U$362, U$445, U$528, U$611, U$694, U$777, U$860, U$943: #_B1#0
U$5, U$84, U$167, U$250, U$333, U$416, U$499, U$582, U$665, U$748, U$831, U$914: #SHLD#0
U$6, U$114, U$197, U$280, U$363, U$446, U$529, U$612, U$695, U$778, U$861, U$944: #_B0#0
U$7, U$115, U$198, U$281, U$364, U$447, U$530, U$613, U$696, U$779, U$862, U$945: #_A0#0
U$8, U$158, U$241, U$324, U$407, U$490, U$573, U$656, U$739, U$822, U$905, U$988: #_A4#0
U$9, U$116, U$199, U$282, U$365, U$448, U$531, U$614, U$697, U$780, U$863, U$946: #_C5#0
U$10, U$117, U$200, U$283, U$366, U$449, U$532, U$615, U$698, U$781, U$864, U$947: #_C4#0
U$11, U$118, U$201, U$284, U$367, U$450, U$533, U$616, U$699, U$782, U$865, U$948: #C7_#0
U$12, U$119, U$202, U$285, U$368, U$451, U$534, U$617, U$700, U$783, U$866, U$949: #A5_#0
U$13, U$120, U$203, U$286, U$369, U$452, U$535, U$618, U$701, U$784, U$867, U$950: #A6_#0
U$14, U$121, U$204, U$287, U$370, U$453, U$536, U$619, U$702, U$785, U$868, U$951: #C6_#0
U$15, U$122, U$205, U$288, U$371, U$454, U$537, U$620, U$703, U$786, U$869, U$952: #C3_#0
U$16, U$123, U$206, U$289, U$372, U$455, U$538, U$621, U$704, U$787, U$870, U$953: #C2_#0
U$17, U$124, U$207, U$290, U$373, U$456, U$539, U$622, U$705, U$788, U$871, U$954: #C1_#0
U$18, U$125, U$208, U$291, U$374, U$457, U$540, U$623, U$706, U$789, U$872, U$955: #C0_#0
U$19, U$105, U$188, U$271, U$354, U$437, U$520, U$603, U$686, U$769, U$852, U$935: #PWR#0
U$20, U$106, U$189, U$272, U$355, U$438, U$521, U$604, U$687, U$770, U$853, U$936: PWR0
U$21, U$85, U$168, U$251, U$334, U$417, U$500, U$583, U$666, U$749, U$832, U$915: #GND_#0
U$22, U$86, U$169, U$252, U$335, U$418, U$501, U$584, U$667, U$750, U$833, U$916: #3V3_#0
U$23, U$58, U$91, U$101, U$174, U$184, U$257, U$267, U$340, U$350, U$423, U$433, U$506, U$516, U$589, U$599, U$672, U$682, U$755, U$765, U$838, U$848, U$921, U$931: MGM240P0
U$24, U$126, U$209, U$292, U$375, U$458, U$541, U$624, U$707, U$790, U$873, U$956: #D0_#0
U$25, U$87, U$170, U$253, U$336, U$419, U$502, U$585, U$668, U$751, U$834, U$917: #_VB#0
U$26, U$88, U$171, U$254, U$337, U$420, U$503, U$586, U$669, U$752, U$835, U$918: #_VU#0
U$27, U$89, U$172, U$255, U$338, U$421, U$504, U$587, U$670, U$753, U$836, U$919: #_EN#0
U$28, U$90, U$173, U$256, U$339, U$422, U$505, U$588, U$671, U$754, U$837, U$920: ##RST##0
U$29, U$92, U$175, U$258, U$341, U$424, U$507, U$590, U$673, U$756, U$839, U$922: SFE_LOGO_FLAME_.2
U$30, U$93, U$176, U$259, U$342, U$425, U$508, U$591, U$674, U$757, U$840, U$923: #0
U$31, U$94, U$177, U$260, U$343, U$426, U$509, U$592, U$675, U$758, U$841, U$924: #1
U$32, U$127, U$210, U$293, U$376, U$459, U$542, U$625, U$708, U$791, U$874, U$957: #D1_#0
U$33, U$157, U$240, U$323, U$406, U$489, U$572, U$655, U$738, U$821, U$904, U$987: #LP#0
U$34, U$142, U$225, U$308, U$391, U$474, U$557, U$640, U$723, U$806, U$889, U$972: #_A6#RX#0
U$35, U$143, U$226, U$309, U$392, U$475, U$558, U$641, U$724, U$807, U$890, U$973: #_C6#POCI#0
U$36, U$144, U$227, U$310, U$393, U$476, U$559, U$642, U$725, U$808, U$891, U$974: #_C3#PICO#0
U$37, U$145, U$228, U$311, U$394, U$477, U$560, U$643, U$726, U$809, U$892, U$975: #_C2#SCK#0
U$38, U$146, U$229, U$312, U$395, U$478, U$561, U$644, U$727, U$810, U$893, U$976: MINI_SIMPLICITY0
U$39, U$128, U$211, U$294, U$377, U$460, U$543, U$626, U$709, U$792, U$875, U$958: #_C1#0
U$40, U$129, U$212, U$295, U$378, U$461, U$544, U$627, U$710, U$793, U$876, U$959: #_C0#0
U$41, U$130, U$213, U$296, U$379, U$462, U$545, U$628, U$711, U$794, U$877, U$960: #_D0#0
U$42, U$131, U$214, U$297, U$380, U$463, U$546, U$629, U$712, U$795, U$878, U$961: #_D1#0
U$43, U$95, U$178, U$261, U$344, U$427, U$510, U$593, U$676, U$759, U$842, U$925: #_GND#0
U$44, U$96, U$179, U$262, U$345, U$428, U$511, U$594, U$677, U$760, U$843, U$926: #_3V3#0
U$45, U$97, U$180, U$263, U$346, U$429, U$512, U$595, U$678, U$761, U$844, U$927: #_#RST##0
U$46, U$132, U$215, U$298, U$381, U$464, U$547, U$630, U$713, U$796, U$879, U$962: #_D2#0
U$47, U$162, U$245, U$328, U$411, U$494, U$577, U$660, U$743, U$826, U$909, U$992: SILICON_LABS_LOGO
U$48, U$133, U$216, U$299, U$382, U$465, U$548, U$631, U$714, U$797, U$880, U$963: #C4_#0
U$49, U$134, U$217, U$300, U$383, U$466, U$549, U$632, U$715, U$798, U$881, U$964: #C5_#0
U$50, U$159, U$242, U$325, U$408, U$491, U$574, U$657, U$740, U$823, U$906, U$989: #A4_#0
U$51, U$135, U$218, U$301, U$384, U$467, U$550, U$633, U$716, U$799, U$882, U$965: #A0_#0
U$52, U$136, U$219, U$302, U$385, U$468, U$551, U$634, U$717, U$800, U$883, U$966: #B0_#0
U$53, U$137, U$220, U$303, U$386, U$469, U$552, U$635, U$718, U$801, U$884, U$967: #B2_#0
U$54, U$138, U$221, U$304, U$387, U$470, U$553, U$636, U$719, U$802, U$885, U$968: #B1_#0
U$55, U$98, U$181, U$264, U$347, U$430, U$513, U$596, U$679, U$762, U$845, U$928: #VBAT_#0
U$56, U$99, U$182, U$265, U$348, U$431, U$514, U$597, U$680, U$763, U$846, U$929: #VUSB_#0
U$57, U$100, U$183, U$266, U$349, U$432, U$515, U$598, U$681, U$764, U$847, U$930: #EN_#0
U$59, U$102, U$185, U$268, U$351, U$434, U$517, U$600, U$683, U$766, U$849, U$932: #MEAS#0
U$60, U$103, U$186, U$269, U$352, U$435, U$518, U$601, U$684, U$767, U$850, U$933: #CHG#0
U$61, U$104, U$187, U$270, U$353, U$436, U$519, U$602, U$685, U$768, U$851, U$934: #I2C#0
U$62, U$153, U$236, U$319, U$402, U$485, U$568, U$651, U$734, U$817, U$900, U$983: #D2_#0
U$63, U$151, U$234, U$317, U$400, U$483, U$566, U$649, U$732, U$815, U$898, U$981: #0#5A#0
U$64, U$152, U$235, U$318, U$401, U$484, U$567, U$650, U$733, U$816, U$899, U$982: #0#1A#0
U$65, U$160, U$243, U$326, U$409, U$492, U$575, U$658, U$741, U$824, U$907, U$990: SEGGER_LOGO
U$66, U$148, U$231, U$314, U$397, U$480, U$563, U$646, U$729, U$812, U$895, U$978: MEAS81
U$67, U$107, U$190, U$273, U$356, U$439, U$522, U$605, U$688, U$771, U$854, U$937: CHG0
U$68, U$108, U$191, U$274, U$357, U$440, U$523, U$606, U$689, U$772, U$855, U$938: STAT0
U$69, U$164, U$247, U$330, U$413, U$496, U$579, U$662, U$745, U$828, U$911, U$994: #JP1#0
U$70, U$109, U$192, U$275, U$358, U$441, U$524, U$607, U$690, U$773, U$856, U$939: RST0
U$71, U$141, U$224, U$307, U$390, U$473, U$556, U$639, U$722, U$805, U$888, U$971: #_A5#TX#0
U$72, U$147, U$230, U$313, U$396, U$479, U$562, U$645, U$728, U$811, U$894, U$977: A80
U$73, U$139, U$222, U$305, U$388, U$471, U$554, U$637, U$720, U$803, U$886, U$969: #SDA#B4_#0
U$74, U$140, U$223, U$306, U$389, U$472, U$555, U$638, U$721, U$804, U$887, U$970: #SCL#B3_#0
U$75, U$149, U$232, U$315, U$398, U$481, U$564, U$647, U$730, U$813, U$896, U$979: ORDERING_INSTRUCTIONS
U$76, U$150, U$233, U$316, U$399, U$482, U$565, U$648, U$731, U$814, U$897, U$980: FOUR_LAYER_WARNING
U$77, U$154, U$237, U$320, U$403, U$486, U$569, U$652, U$735, U$818, U$901, U$984: #D3_#0
U$78, U$155, U$238, U$321, U$404, U$487, U$570, U$653, U$736, U$819, U$902, U$985: DBG0
U$79, U$156, U$239, U$322, U$405, U$488, U$571, U$654, U$737, U$820, U$903, U$986: #_C7#FREE#0
U$80, U$165, U$248, U$331, U$414, U$497, U$580, U$663, U$746, U$829, U$912, U$995: A0
U$81, U$166, U$249, U$332, U$415, U$498, U$581, U$664, U$747, U$830, U$913, U$996: B0
U$82, U$161, U$244, U$327, U$410, U$493, U$576, U$659, U$742, U$825, U$908, U$991: #D3#4
U$83, U$163, U$246, U$329, U$412, U$495, U$578, U$661, U$744, U$827, U$910, U$993: #CHG_I#0
Y1, Y2, Y3, Y4, Y5, Y6, Y7, Y8, Y9, Y10, Y11, Y12: CRYSTAL-48MHZ; CRYSTAL-SMD-2.0X1.6MM-ECS

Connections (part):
3.3V: C1.1, C2.1, C4.1, C5.1, C6.1, C14.1, C18.1, C19.1, C20.1, C21.1, FB1.2, I2C.2, J1.27, J3.2, J5.4, J7.1, PWR.2, R1.2, R12.2, R14.2, R16.2, R17.2, R19.2, TP1.1, U1.15, U2.5, U3.C6, U3.C9, U3.G3, U3.H11, U3.J11, U3.K3, U3.L4, U3.L7, U6.8, U7.3, U7.8
3.3V1: C23.1, C27.1, C28.1, C30.1, C31.1, C32.1, C39.1, C40.1, C41.1, C42.1, FB2.2, I2C1.2, J6.27, J10.2, J11.4, J12.1, PWR1.2, R33.2, R34.2, R36.2, R37.2, R38.2, R40.2, TP15.1, U8.15, U9.5, U12.C6, U12.C9, U12.G3, U12.H11, U12.J11, U12.K3, U12.L4, U12.L7, U13.8, U14.3, U14.8
3.3V2: C44.1, C48.1, C49.1, C51.1, C52.1, C53.1, C60.1, C61.1, C62.1, C63.1, FB3.2, I2C2.2, J13.27, J16.2, J17.4, J18.1, PWR2.2, R54.2, R55.2, R57.2, R58.2, R59.2, R61.2, TP29.1, U15.15, U16.5, U19.C6, U19.C9, U19.G3, U19.H11, U19.J11, U19.K3, U19.L4, U19.L7, U20.8, U21.3, U21.8
3.3V3: C65.1, C69.1, C70.1, C72.1, C73.1, C74.1, C81.1, C82.1, C83.1, C84.1, FB4.2, I2C3.2, J19.27, J22.2, J23.4, J24.1, PWR3.2, R75.2, R76.2, R78.2, R79.2, R80.2, R82.2, TP43.1, U22.15, U23.5, U26.C6, U26.C9, U26.G3, U26.H11, U26.J11, U26.K3, U26.L4, U26.L7, U27.8, U28.3, U28.8
3.3V4: C86.1, C90.1, C91.1, C93.1, C94.1, C95.1, C102.1, C103.1, C104.1, C105.1, FB5.2, I2C4.2, J25.27, J28.2, J29.4, J30.1, PWR4.2, R96.2, R97.2, R99.2, R100.2, R101.2, R103.2, TP57.1, U29.15, U30.5, U33.C6, U33.C9, U33.G3, U33.H11, U33.J11, U33.K3, U33.L4, U33.L7, U34.8, U35.3, U35.8
3.3V5: C107.1, C111.1, C112.1, C114.1, C115.1, C116.1, C123.1, C124.1, C125.1, C126.1, FB6.2, I2C5.2, J31.27, J34.2, J35.4, J36.1, PWR5.2, R117.2, R118.2, R120.2, R121.2, R122.2, R124.2, TP71.1, U36.15, U37.5, U40.C6, U40.C9, U40.G3, U40.H11, U40.J11, U40.K3, U40.L4, U40.L7, U41.8, U42.3, U42.8
3.3V6: C128.1, C132.1, C133.1, C135.1, C136.1, C137.1, C144.1, C145.1, C146.1, C147.1, FB7.2, I2C6.2, J37.27, J40.2, J41.4, J42.1, PWR6.2, R138.2, R139.2, R141.2, R142.2, R143.2, R145.2, TP85.1, U43.15, U44.5, U47.C6, U47.C9, U47.G3, U47.H11, U47.J11, U47.K3, U47.L4, U47.L7, U48.8, U49.3, U49.8
3.3V7: C149.1, C153.1, C154.1, C156.1, C157.1, C158.1, C165.1, C166.1, C167.1, C168.1, FB8.2, I2C7.2, J43.27, J46.2, J47.4, J48.1, PWR7.2, R159.2, R160.2, R162.2, R163.2, R164.2, R166.2, TP99.1, U50.15, U51.5, U54.C6, U54.C9, U54.G3, U54.H11, U54.J11, U54.K3, U54.L4, U54.L7, U55.8, U56.3, U56.8
3.3V8: C170.1, C174.1, C175.1, C177.1, C178.1, C179.1, C186.1, C187.1, C188.1, C189.1, FB9.2, I2C8.2, J49.27, J52.2, J53.4, J54.1, PWR8.2, R180.2, R181.2, R183.2, R184.2, R185.2, R187.2, TP113.1, U57.15, U58.5, U61.C6, U61.C9, U61.G3, U61.H11, U61.J11, U61.K3, U61.L4, U61.L7, U62.8, U63.3, U63.8
3.3V9: C191.1, C195.1, C196.1, C198.1, C199.1, C200.1, C207.1, C208.1, C209.1, C210.1, FB10.2, I2C9.2, J55.27, J58.2, J59.4, J60.1, PWR9.2, R201.2, R202.2, R204.2, R205.2, R206.2, R208.2, TP127.1, U64.15, U65.5, U68.C6, U68.C9, U68.G3, U68.H11, U68.J11, U68.K3, U68.L4, U68.L7, U69.8, U70.3, U70.8
3.3V10: C212.1, C216.1, C217.1, C219.1, C220.1, C221.1, C228.1, C229.1, C230.1, C231.1, FB11.2, I2C10.2, J61.27, J64.2, J65.4, J66.1, PWR10.2, R222.2, R223.2, R225.2, R226.2, R227.2, R229.2, TP141.1, U71.15, U72.5, U75.C6, U75.C9, U75.G3, U75.H11, U75.J11, U75.K3, U75.L4, U75.L7, U76.8, U77.3, U77.8
3.3V11: C233.1, C237.1, C238.1, C240.1, C241.1, C242.1, C249.1, C250.1, C251.1, C252.1, FB12.2, I2C11.2, J67.27, J70.2, J71.4, J72.1, PWR11.2, R243.2, R244.2, R246.2, R247.2, R248.2, R250.2, TP155.1, U78.15, U79.5, U82.C6, U82.C9, U82.G3, U82.H11, U82.J11, U82.K3, U82.L4, U82.L7, U83.8, U84.3, U84.8
!DBG_RESET!: TP3.1, U3.L8, U3.M7
!DBG_RESET!1: TP17.1, U12.L8, U12.M7
!DBG_RESET!2: TP31.1, U19.L8, U19.M7
!DBG_RESET!3: TP45.1, U26.L8, U26.M7
!DBG_RESET!4: TP59.1, U33.L8, U33.M7
!DBG_RESET!5: TP73.1, U40.L8, U40.M7
!DBG_RESET!6: TP87.1, U47.L8, U47.M7
!DBG_RESET!7: TP101.1, U54.L8, U54.M7
!DBG_RESET!8: TP115.1, U61.L8, U61.M7
!DBG_RESET!9: TP129.1, U68.L8, U68.M7
!DBG_RESET!10: TP143.1, U75.L8, U75.M7
!DBG_RESET!11: TP157.1, U82.L8, U82.M7
!RESET!: J7.3, JP1.2, S1.3, S1.4, U1.31, U3.D1
!RESET!1: J12.3, JP2.2, S2.3, S2.4, U8.31, U12.D1
!RESET!2: J18.3, JP3.2, S3.3, S3.4, U15.31, U19.D1
!RESET!3: J24.3, JP4.2, S4.3, S4.4, U22.31, U26.D1
!RESET!4: J30.3, JP5.2, S5.3, S5.4, U29.31, U33.D1
!RESET!5: J36.3, JP6.2, S6.3, S6.4, U36.31, U40.D1
!RESET!6: J42.3, JP7.2, S7.3, S7.4, U43.31, U47.D1
!RESET!7: J48.3, JP8.2, S8.3, S8.4, U50.31, U54.D1
!RESET!8: J54.3, JP9.2, S9.3, S9.4, U57.31, U61.D1
!RESET!9: J60.3, JP10.2, S10.3, S10.4, U64.31, U68.D1
!RESET!10: J66.3, JP11.2, S11.3, S11.4, U71.31, U75.D1
!RESET!11: J72.3, JP12.2, S12.3, S12.4, U78.31, U82.D1
!SD_CS!/PA01: J11.2, R40.1, U8.16
!SD_CS!/PA02: J17.2, R61.1, U15.16
!SD_CS!/PA03: J23.2, R82.1, U22.16
!SD_CS!/PA04: J29.2, R103.1, U29.16
!SD_CS!/PA05: J35.2, R124.1, U36.16
!SD_CS!/PA06: J41.2, R145.1, U43.16
!SD_CS!/PA07: J5.2, R19.1, U1.16
!SD_CS!/PA08: J47.2, R166.1, U50.16
!SD_CS!/PA09: J53.2, R187.1, U57.16
!SD_CS!/PA10: J59.2, R208.1, U64.16
!SD_CS!/PA11: J65.2, R229.1, U71.16
!SD_CS!/PA12: J71.2, R250.1, U78.16
A0: D3_ISO.2, J1.24, JP1.1
A1: D3_ISO1.2, J6.24, JP2.1
A2: D3_ISO2.2, J13.24, JP3.1
A3: D3_ISO3.2, J19.24, JP4.1
A4: D3_ISO4.2, J25.24, JP5.1
A5: D3_ISO5.2, J31.24, JP6.1
A6: D3_ISO6.2, J37.24, JP7.1
A7: D3_ISO7.2, J43.24, JP8.1
A8: D3_ISO8.2, J49.24, JP9.1
A9: D3_ISO9.2, J55.24, JP10.1
A10: D3_ISO10.2, J61.24, JP11.1
A11: D3_ISO11.2, J67.24, JP12.1
DBG_CS: R17.1, TP10.1, U3.B1, U3.B2, U7.1
DBG_CS1: R38.1, TP24.1, U12.B1, U12.B2, U14.1
DBG_CS2: R59.1, TP38.1, U19.B1, U19.B2, U21.1
DBG_CS3: R80.1, TP52.1, U26.B1, U26.B2, U28.1
DBG_CS4: R101.1, TP66.1, U33.B1, U33.B2, U35.1
DBG_CS5: R122.1, TP80.1, U40.B1, U40.B2, U42.1
DBG_CS6: R143.1, TP94.1, U47.B1, U47.B2, U49.1
DBG_CS7: R164.1, TP108.1, U54.B1, U54.B2, U56.1
DBG_CS8: R185.1, TP122.1, U61.B1, U61.B2, U63.1
DBG_CS9: R206.1, TP136.1, U68.B1, U68.B2, U70.1
DBG_CS10: R227.1, TP150.1, U75.B1, U75.B2, U77.1
DBG_CS11: R248.1, TP164.1, U82.B1, U82.B2, U84.1
DBG_LED_PWR: C12.1, D6.A, U3.A12
DBG_LED_PWR1: C38.1, D13.A, U12.A12
DBG_LED_PWR2: C59.1, D20.A, U19.A12
DBG_LED_PWR3: C80.1, D27.A, U26.A12
DBG_LED_PWR4: C101.1, D34.A, U33.A12
DBG_LED_PWR5: C122.1, D41.A, U40.A12
DBG_LED_PWR6: C143.1, D48.A, U47.A12
DBG_LED_PWR7: C164.1, D55.A, U54.A12
DBG_LED_PWR8: C185.1, D62.A, U61.A12
DBG_LED_PWR9: C206.1, D69.A, U68.A12
DBG_LED_PWR10: C227.1, D76.A, U75.A12
DBG_LED_PWR11: C248.1, D83.A, U82.A12
DBG_PICO: TP7.1, U3.C3, U7.5
DBG_PICO1: TP21.1, U12.C3, U14.5
DBG_PICO2: TP35.1, U19.C3, U21.5
DBG_PICO3: TP49.1, U26.C3, U28.5
DBG_PICO4: TP63.1, U33.C3, U35.5
DBG_PICO5: TP77.1, U40.C3, U42.5
DBG_PICO6: TP91.1, U47.C3, U49.5
DBG_PICO7: TP105.1, U54.C3, U56.5
DBG_PICO8: TP119.1, U61.C3, U63.5
DBG_PICO9: TP133.1, U68.C3, U70.5
DBG_PICO10: TP147.1, U75.C3, U77.5
DBG_PICO11: TP161.1, U82.C3, U84.5
DBG_POCI: TP8.1, U3.A4, U3.B3, U7.2
DBG_POCI1: TP22.1, U12.A4, U12.B3, U14.2
DBG_POCI2: TP36.1, U19.A4, U19.B3, U21.2
DBG_POCI3: TP50.1, U26.A4, U26.B3, U28.2
DBG_POCI4: TP64.1, U33.A4, U33.B3, U35.2
DBG_POCI5: TP78.1, U40.A4, U40.B3, U42.2
DBG_POCI6: TP92.1, U47.A4, U47.B3, U49.2
DBG_POCI7: TP106.1, U54.A4, U54.B3, U56.2
DBG_POCI8: TP120.1, U61.A4, U61.B3, U63.2
DBG_POCI9: TP134.1, U68.A4, U68.B3, U70.2
DBG_POCI10: TP148.1, U75.A4, U75.B3, U77.2
DBG_POCI11: TP162.1, U82.A4, U82.B3, U84.2
DBG_RX: TP13.1, U3.A1
DBG_RX1: TP27.1, U12.A1
DBG_RX2: TP41.1, U19.A1
DBG_RX3: TP55.1, U26.A1
DBG_RX4: TP69.1, U33.A1
DBG_RX5: TP83.1, U40.A1
DBG_RX6: TP97.1, U47.A1
DBG_RX7: TP111.1, U54.A1
DBG_RX8: TP125.1, U61.A1
DBG_RX9: TP139.1, U68.A1
DBG_RX10: TP153.1, U75.A1
DBG_RX11: TP167.1, U82.A1
DBG_SCK: TP9.1, U3.A3, U7.6
DBG_SCK1: TP23.1, U12.A3, U14.6
DBG_SCK2: TP37.1, U19.A3, U21.6
DBG_SCK3: TP51.1, U26.A3, U28.6
DBG_SCK4: TP65.1, U33.A3, U35.6
DBG_SCK5: TP79.1, U40.A3, U42.6
DBG_SCK6: TP93.1, U47.A3, U49.6
DBG_SCK7: TP107.1, U54.A3, U56.6
DBG_SCK8: TP121.1, U61.A3, U63.6
DBG_SCK9: TP135.1, U68.A3, U70.6
DBG_SCK10: TP149.1, U75.A3, U77.6
DBG_SCK11: TP163.1, U82.A3, U84.6
DBG_SCL: R16.1, TP12.1, U3.H13, U6.6
DBG_SCL1: R37.1, TP26.1, U12.H13, U13.6
DBG_SCL2: R58.1, TP40.1, U19.H13, U20.6
DBG_SCL3: R79.1, TP54.1, U26.H13, U27.6
DBG_SCL4: R100.1, TP68.1, U33.H13, U34.6
DBG_SCL5: R121.1, TP82.1, U40.H13, U41.6
DBG_SCL6: R142.1, TP96.1, U47.H13, U48.6
DBG_SCL7: R163.1, TP110.1, U54.H13, U55.6
DBG_SCL8: R184.1, TP124.1, U61.H13, U62.6
DBG_SCL9: R205.1, TP138.1, U68.H13, U69.6
DBG_SCL10: R226.1, TP152.1, U75.H13, U76.6
DBG_SCL11: R247.1, TP166.1, U82.H13, U83.6
DBG_SDA: R12.1, TP11.1, U3.G13, U3.H12, U3.J12, U6.5
DBG_SDA1: R36.1, TP25.1, U12.G13, U12.H12, U12.J12, U13.5
DBG_SDA2: R57.1, TP39.1, U19.G13, U19.H12, U19.J12, U20.5
DBG_SDA3: R78.1, TP53.1, U26.G13, U26.H12, U26.J12, U27.5
DBG_SDA4: R99.1, TP67.1, U33.G13, U33.H12, U33.J12, U34.5
DBG_SDA5: R120.1, TP81.1, U40.G13, U40.H12, U40.J12, U41.5
DBG_SDA6: R141.1, TP95.1, U47.G13, U47.H12, U47.J12, U48.5
DBG_SDA7: R162.1, TP109.1, U54.G13, U54.H12, U54.J12, U55.5
DBG_SDA8: R183.1, TP123.1, U61.G13, U61.H12, U61.J12, U62.5
DBG_SDA9: R204.1, TP137.1, U68.G13, U68.H12, U68.J12, U69.5
DBG_SDA10: R225.1, TP151.1, U75.G13, U75.H12, U75.J12, U76.5
DBG_SDA11: R246.1, TP165.1, U82.G13, U82.H12, U82.J12, U83.5
DBG_SWCLK: TP4.1, U3.C10
DBG_SWCLK1: TP18.1, U12.C10
DBG_SWCLK2: TP32.1, U19.C10
DBG_SWCLK3: TP46.1, U26.C10
DBG_SWCLK4: TP60.1, U33.C10
DBG_SWCLK5: TP74.1, U40.C10
DBG_SWCLK6: TP88.1, U47.C10
DBG_SWCLK7: TP102.1, U54.C10
DBG_SWCLK8: TP116.1, U61.C10
DBG_SWCLK9: TP130.1, U68.C10
DBG_SWCLK10: TP144.1, U75.C10
DBG_SWCLK11: TP158.1, U82.C10
DBG_SWDIO: TP2.1, U3.A9, U3.B10
DBG_SWDIO1: TP16.1, U12.A9, U12.B10
DBG_SWDIO2: TP30.1, U19.A9, U19.B10
DBG_SWDIO3: TP44.1, U26.A9, U26.B10
DBG_SWDIO4: TP58.1, U33.A9, U33.B10
DBG_SWDIO5: TP72.1, U40.A9, U40.B10
DBG_SWDIO6: TP86.1, U47.A9, U47.B10
DBG_SWDIO7: TP100.1, U54.A9, U54.B10
DBG_SWDIO8: TP114.1, U61.A9, U61.B10
DBG_SWDIO9: TP128.1, U68.A9, U68.B10
DBG_SWDIO10: TP142.1, U75.A9, U75.B10
DBG_SWDIO11: TP156.1, U82.A9, U82.B10
DBG_SWO: TP6.1, U3.A10
DBG_SWO1: TP20.1, U12.A10
DBG_SWO2: TP34.1, U19.A10
DBG_SWO3: TP48.1, U26.A10
DBG_SWO4: TP62.1, U33.A10
DBG_SWO5: TP76.1, U40.A10
DBG_SWO6: TP90.1, U47.A10
DBG_SWO7: TP104.1, U54.A10
DBG_SWO8: TP118.1, U61.A10
DBG_SWO9: TP132.1, U68.A10
DBG_SWO10: TP146.1, U75.A10
DBG_SWO11: TP160.1, U82.A10
DBG_TX: TP14.1, U3.A2
DBG_TX1: TP28.1, U12.A2
DBG_TX2: TP42.1, U19.A2
DBG_TX3: TP56.1, U26.A2
DBG_TX4: TP70.1, U33.A2
DBG_TX5: TP84.1, U40.A2
DBG_TX6: TP98.1, U47.A2
DBG_TX7: TP112.1, U54.A2
DBG_TX8: TP126.1, U61.A2
DBG_TX9: TP140.1, U68.A2
DBG_TX10: TP154.1, U75.A2
DBG_TX11: TP168.1, U82.A2
DBG_WAKE: D8.A, U3.E1
DBG_WAKE1: D14.A, U12.E1
DBG_WAKE2: D21.A, U19.E1
DBG_WAKE3: D28.A, U26.E1
DBG_WAKE4: D35.A, U33.E1
DBG_WAKE5: D42.A, U40.E1
DBG_WAKE6: D49.A, U47.E1
DBG_WAKE7: D56.A, U54.E1
DBG_WAKE8: D63.A, U61.E1
DBG_WAKE9: D70.A, U68.E1
DBG_WAKE10: D77.A, U75.E1
DBG_WAKE11: D84.A, U82.E1
DBG_WP: R14.1, U3.F13, U6.7
DBG_WP1: R34.1, U12.F13, U13.7
DBG_WP2: R55.1, U19.F13, U20.7
DBG_WP3: R76.1, U26.F13, U27.7
DBG_WP4: R97.1, U33.F13, U34.7
DBG_WP5: R118.1, U40.F13, U41.7
DBG_WP6: R139.1, U47.F13, U48.7
DBG_WP7: R160.1, U54.F13, U55.7
DBG_WP8: R181.1, U61.F13, U62.7
DBG_WP9: R202.1, U68.F13, U69.7
DBG_WP10: R223.1, U75.F13, U76.7
DBG_WP11: R244.1, U82.F13, U83.7
EN: J1.11, R2.2, U2.3
EN1: J6.11, R22.2, U9.3
EN2: J13.11, R43.2, U16.3
EN3: J19.11, R64.2, U23.3
EN4: J25.11, R85.2, U30.3
EN5: J31.11, R106.2, U37.3
EN6: J37.11, R127.2, U44.3
EN7: J43.11, R148.2, U51.3
EN8: J49.11, R169.2, U58.3
EN9: J55.11, R190.2, U65.3
EN10: J61.11, R211.2, U72.3
EN11: J67.11, R232.2, U79.3
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

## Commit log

2022-06-13 Add initial schematic and layout
    [Thing_Plus_MGM240P.brd, Thing_Plus_MGM240P.sch]
2022-06-15 Schematic and board updates
    Disconnect RTS and CTS pins
    Add status LED
    Complete more of the routing and component placement
    [Thing_Plus_MGM240P.brd, Thing_Plus_MGM240P.sch]
2022-06-15 Finalize initial schematic and board
    Clean up schematic and finalize nets
    Finish routing board (needs improved GND continuity
    [Thing_Plus_MGM240P.brd, Thing_Plus_MGM240P.sch]
2022-06-15 Add polish
    Improve GND continuity
    Fix and approve DRC errors
    Add SFE flame and OSHW logo to top silk
    Add pin and jumper labels to bottom silk
    [Thing_Plus_MGM240P.brd, Thing_Plus_MGM240P.sch]
2022-06-15 Update voltage regulator
    [Thing_Plus_MGM240P.brd, Thing_Plus_MGM240P.sch]
2022-06-16 Design review updates
    Add reset button
    Add power LED
    Pour USB shield on bottom too
    Increase VUSB trace to 20mil
    Add silk labels for LEDs
    Add version number to copper
    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
    [Thing_Plus_MGM240P.brd, Thing_Plus_MGM240P.sch]
2022-06-16 Design review updates
    Chang USB connector to 2-layer version
    Fix gague typo in schematic
    Remove UART flow control nets from J-Link
    Spread out J-Link caps in schematic
    Remove right angles from VDDJ trace and straighten out
    Fix acid trap
    Move reset button and 2 caps away from J-Link chip
    Move POCI to top layer at SD card
    Fix USB width before ESD protection
    Thicker USB ESD trace
    [Thing_Plus_MGM240P.brd, Thing_Plus_MGM240P.sch]
2022-06-17 Design review updates
    Change to 4-layer board for better EMC and routing
    Remove excessive GND vias now that it's 4 layers
    Add label to reset button in silk
    Add 10uF cap for SD card
    Change net names to represent MGM240P port names rather than Arduino names
    Connect uSD CS pin to PA07
    Fix acid traps
    Reposition MEAS to be off-grid to prevent confusion
    [Thing_Plus_MGM240P.brd, Thing_Plus_MGM240P.sch]
2022-06-17 Create library part for J-Link 6 Pin Adapter
2022-06-17 Update silk width of MGM240P
    Board ULP was giving warning
2022-06-17 Design review and checklist updates
    Swap J-Link test points for new part
    Change size of STAT silk and add pin number
    Adjust fuel gauge cap position
    Adjust board name silk positions
    Add ordering instructions (4 layer board)
    Add layer numbers in copper
    Move LED jumper out of standoff keepout
    Update charge current silk labels to read "0.5A" instead of 500
    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
    [Thing_Plus_MGM240P.brd, Thing_Plus_MGM240P.sch]
2022-06-17 Add name and value to J-Link connector footprint
2022-06-17 Design review updates
    Change USB-C connector to 4-layer version
    Add units to measures
    Update J-Link footprint
    [Thing_Plus_MGM240P.brd, Thing_Plus_MGM240P.sch]
2022-06-20 Minor board updates
    Shift MEAS jumper to not interfere with R4
    Add GND via under J-Link
    Add SHLD via to fix air wire between layers
    [Thing_Plus_MGM240P.brd]
2022-07-11 Remove J-Link 6-pin adapter part
    Not going to use it
2022-07-11 Update board with new debugger chip
    Middle region of board had to be completely rerouted
    [Thing_Plus_MGM240P.brd, Thing_Plus_MGM240P.sch]
2022-07-11 Finish debugger power circuitry
    [Thing_Plus_MGM240P.brd, Thing_Plus_MGM240P.sch]
2022-07-12 Serial flash and routing updates
    Update serial flash chip and routing for it
    Change routing of debugger chip to not require 3.5 mil traces
    [Thing_Plus_MGM240P.brd, Thing_Plus_MGM240P.sch]
2022-07-13 Minor routing improvements
    Route TX through unused pin on debugger chip
    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
    [Thing_Plus_MGM240P.brd, Thing_Plus_MGM240P.sch]
2022-07-14 Update board
    Update EFM32 and MGM240P symbols
    Remove JTAG labels from net names
    [Thing_Plus_MGM240P.brd, Thing_Plus_MGM240P.sch]
2022-07-14 Fix merge issue
    Forgot to pull changes from home, whoops...
    [Thing_Plus_MGM240P.sch]
2022-07-14 Checklist and design review updates
    Add warning about holding GPIO pins high while chip not powered
    Change status LED resistor value
    Fix EFM32 name and value not appearing in board
    Fix U2 part number missing in schematic
    Move USB connector to left side of schematic
    Move C7 to fit U3D part number in schematic
    [Thing_Plus_MGM240P.brd, Thing_Plus_MGM240P.sch]
2022-07-14 Design review updates
    Make EFM32 symbol D wider to not have pin names interleaved
    Tweak location of test points in schematic to match relative locations on board
    Route pads from centers better
    Adjust CC resistor positions
    Widen V_USB trace under USB connector and add more vias
    Change V_USB trace in power layer to wider polygon
    Increase isolate of 3V3 pour
    Move R2 away from U2
    Add bRestrict to prevent GND fingers from pouring between debug traces
    Move R4 outside of U4 courtyard
    Shift status LED to space silk a bit more
    Adjust SFE flame silk to not touch C7 silk
    Fix measures on right side
    [Thing_Plus_MGM240P.brd, Thing_Plus_MGM240P.sch]
2022-07-14 Design review updates
    Fix measurements on right side of board
    Rename VDDJ net from VDD to VDDJ
    Add "FREE" to C7 silk
    Replace J Link power control circuitry with a NC jumper
    Move reset button next to battery connector
    Improve continuity of 3V3 pour
    [Thing_Plus_MGM240P.brd, Thing_Plus_MGM240P.sch]
2022-07-15 Update new parts
    Add PROD_ID
    Add descriptions
    [Thing_Plus_MGM240P.brd, Thing_Plus_MGM240P.sch]
2022-07-18 Design review updates
    Shift debug circuitry downwards
    Add 48MHz crystal
    Fix V_BATT and V_USB being flipped on Thing Plus pinout
    Add pullup resistors for debugger I2C and CS lines
    Add filter caps for debugger chip
    Change C7 to X7R 0603 for better derating performance
    Rename PTI_SYNC to PTI_FRAME
    [Thing_Plus_MGM240P.brd, Thing_Plus_MGM240P.sch]
2022-07-18 Design review updates
    Fix V_BATT and V_USB label locations
    Move VDDJ label to not interfere with GND label
    Move crystal away from C9
    [Thing_Plus_MGM240P.brd]
2022-07-18 Add PROD_ID to crystal
    [Thing_Plus_MGM240P.brd, Thing_Plus_MGM240P.sch]
2022-07-19 Change debugger power circuitry
    Remove VDDJ jumper
    Remove VDDJ net and replace with 3V3
    Add DBG_WAKE net and circuitry, which controls sleep state of debugger chip
    [Thing_Plus_MGM240P.brd, Thing_Plus_MGM240P.sch]
2022-07-19 Design review updates
    Remove VDDJ label from silk
    Add jumper to debugger power control circuit for USB battery applications
    [Thing_Plus_MGM240P.brd, Thing_Plus_MGM240P.sch]
2022-07-19 Add proto production files
    [Thing_Plus_MGM240P-Panel.GBL, Thing_Plus_MGM240P-Panel.GBO, Thing_Plus_MGM240P-Panel.GBP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]
2022-08-01 Testing fixes
    Update version number to v02
    Mirror MX8035 footprint (whoops...)
    Swap R15 for 2k2 (turns out VREGO is 3V3, not 5V)
    Add trace to 3V3 pour to connect between V_USB and N$24
    [Thing_Plus_MGM240P.brd, Thing_Plus_MGM240P.sch]
2022-08-01 Design review updates
    Adjust DBG_SCK trace
    Remove extra GND trace of C6
    [Thing_Plus_MGM240P.brd]
2022-08-02 Flip DBG TX and RX
    [Thing_Plus_MGM240P.brd, Thing_Plus_MGM240P.sch]
2022-08-02 Swap PA04 and PA07
    [Thing_Plus_MGM240P.brd, Thing_Plus_MGM240P.sch]
2022-08-02 Update proto production files for v02
    [Thing_Plus_MGM240P-Panel.brd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]
2022-09-07 Design review updates
    Add GND vias along antenna cutout edge
    Add extra GND vias near MGM240P GND pads
    Add pullup resistor to SD card CS pin
    Add extra GND vias between I2C and SPI traces on bottom
    Widen DECOUPLE trace
    Add series resistors to MGM240P's RX inputs to prevent contention between debugger, Mini Simplicity connector, and Thing Plus RX pin
    [Thing_Plus_MGM240P.brd, Thing_Plus_MGM240P.sch]
2022-09-07 Design review updates
    Change voltage regulator to specify maximum input voltage only
    Add Segger logo
    Move traces away from jumpers to prevent accidental cutting
    [Thing_Plus_MGM240P.brd, Thing_Plus_MGM240P.sch]
2022-09-07 Fix air wire
    [Thing_Plus_MGM240P.brd]
2022-09-07 Update revision number to v10
    [Thing_Plus_MGM240P.brd, Thing_Plus_MGM240P.sch]
2022-09-08 Design review updates
    Add "ENIG Finish" to ordering instructions
    Add jumpers for rerouting reset line to A0 pin
    [Thing_Plus_MGM240P.brd, Thing_Plus_MGM240P.sch]
2022-09-09 Add Silicon Labs logo
    [Thing_Plus_MGM240P.brd]
2022-09-09 Add text to RST and D3_ISO jumpers
    [Thing_Plus_MGM240P.sch]
2022-09-09 Design review updates
    Move RST jumper to align with D3_ISO jumper
    Add silk label to CHG_I jumper
    Move R20 left 25 mils
    [Thing_Plus_MGM240P.brd]
2022-09-09 Design review updates
    Nudge RX/PA06 away from N$25
    Add text to schematic explaining escape routing connections
    Change RST jumper to "JP1" to make people read the docs
    Remove "Thing Plus" from bottom silkscreen
    [Thing_Plus_MGM240P.brd, Thing_Plus_MGM240P.sch]
2022-09-09 Design review changes
    Change JP1 silk
    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
    [Thing_Plus_MGM240P.brd]
2022-09-09 Add v10 production files
    [Thing_Plus_MGM240P-Panel.brd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]
2022-09-09 Remove extraneous silk
    [Thing_Plus_MGM240P.brd]
2022-09-09 Update v10 production files
    [Thing_Plus_MGM240P-Panel.brd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]
2022-10-06 Change R3 from 10k to 100k
    Improves low power consumption
    [Thing_Plus_MGM240P.brd, Thing_Plus_MGM240P.sch]
2023-03-29 Remove library files
    Parts are in SFE Eagle library, update parts in design
    [Thing_Plus_MGM240P.brd, Thing_Plus_MGM240P.sch]

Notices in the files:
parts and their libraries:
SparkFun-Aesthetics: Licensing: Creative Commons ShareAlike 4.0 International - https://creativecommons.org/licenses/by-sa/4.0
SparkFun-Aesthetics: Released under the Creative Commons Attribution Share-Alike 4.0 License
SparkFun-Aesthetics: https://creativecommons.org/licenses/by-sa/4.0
